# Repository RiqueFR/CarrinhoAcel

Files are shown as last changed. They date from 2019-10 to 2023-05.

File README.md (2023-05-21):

# CarrinhoAcel

Este projeto consiste no projeto de um robô/carrinho controlado remotamente por meio de comunicação Bluetooth e os dados lidos de um acelorômetro, que foi preso a uma luva sendo assim responsável por direcionar o robô conforme a inclinação da mão do condutor.</br>
O projeto foi desenvolvido para a disciplina de Projeto Integrado de Computação, no segundo período do curso de Engenharia de Computação da UFES.

## Esquemático

No diretório "Esq_Eagle" é possível encontrar o esquemático eletrônico desenvolvido tanto para a luva quanto para o carrinho, em seus respectivos diretórios.

## Funcionamento

O projeto funciona basicamente da seguinte forma, um Arduíno lê os dados do sensor de acelerômetro, transforma esses dados em uma direção, representada por um caractér, e um valor entre 0 e 1, que representa o quão inclinada está a luva.
Esses dado são passados via Bluetooth para outro Arduíno que está no robô, e ele controla a velocidade dos motores de acordo com a direção e o decimal recebido, que representa uma porcentagem da velocidade dele.

## Outros

É possível ver mais informações do projeto no documento "Henrique_Thiago_Henrique.pdf", que foi o arquivo enviado como relatório para o professor da disciplina.

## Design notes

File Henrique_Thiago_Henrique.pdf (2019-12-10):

UNIVERSIDADE FEDERAL DO ESPÍRITO SANTO CAMPUS VITÓRIA - GOIABEIRAS

Alunos: Henrique Faria Ribeiro, Henrique Paulino Cruz e Thiago Tineli Paiva Disciplina: Projeto Integrador em Computação I
Docente: Vinicius Fernandes Soares Mota
Data: 11/12/2019

PROJETO

O projeto inicialmente foi desenvolvido na parte de software, para o controle da ponte H, projeção da comunicação via Bluetooth e o tratamento de valores do acelerômetro.
Após o desenvolvimento dessa parte, foi adaptado um carrinho, para o uso no projeto, também foi realizado os esquemáticos para a luva e o carrinho.
Finalmente, ocorreu a integração entre Hardware e Software, com a confecção das placas para o projeto e sua implementação nas peças.

ESQUEMÁTICOS

❏ Ligação na luva

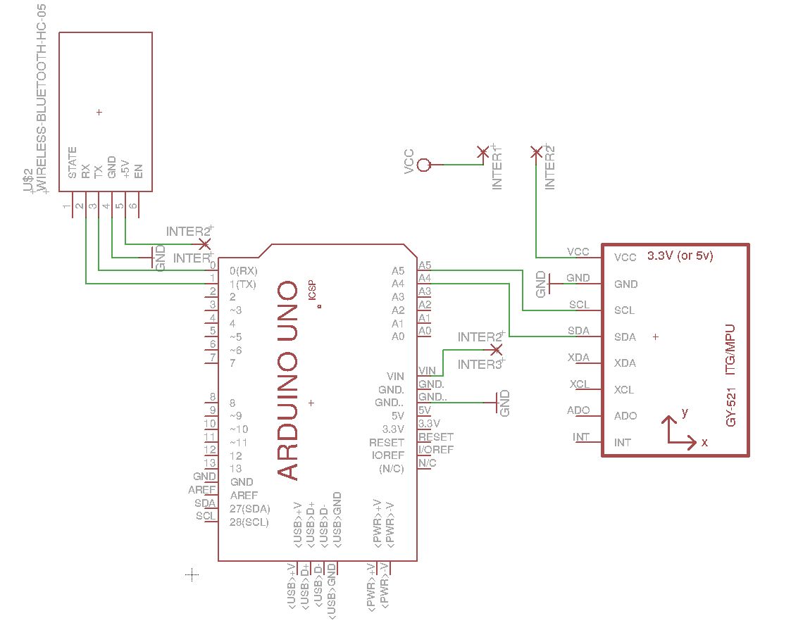
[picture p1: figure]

❏ Ligação no carrinho

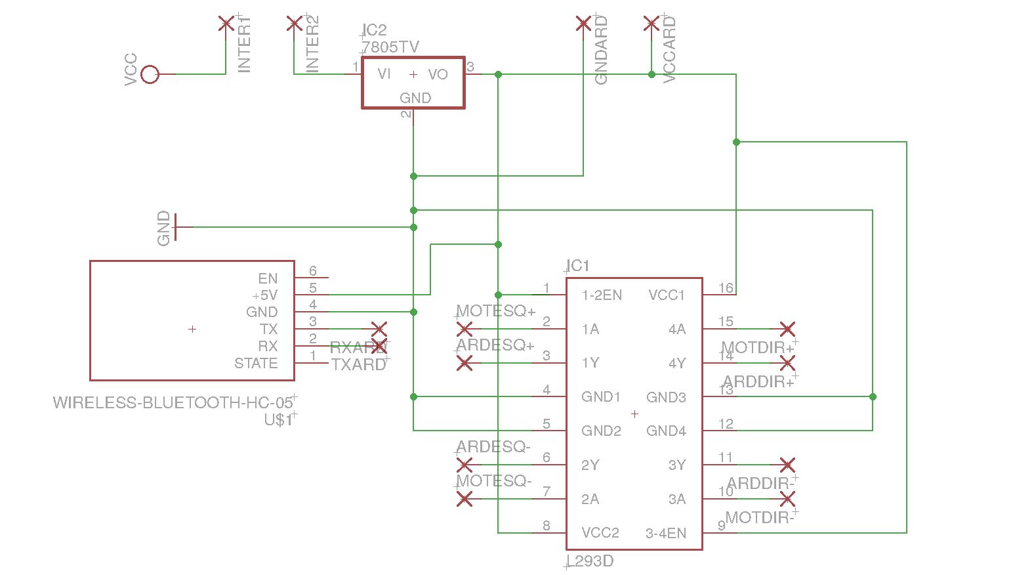
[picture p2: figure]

Obs: nesse esquemático as portas que ligariam no arduino estão representados como PADs, pois se fosse colocado o arduíno no esquemático ele ficaria menos legível, atrapalhando a compreensão.

COMPONENTES

Eletrônico:
❏ Arduino UNO - 2 unidades
❏ Ponte H - 1 unidade
❏ Bateria - 4 células de bateria de notebook ❏ Motor com redução e rodas - 2 unidades ❏ Acelerômetro - 1 unidade
❏ Bluetooth HC-05 - 2 unidades
❏ Chaves - 2 unidades
❏ Placa de circuito impresso - 2 unidades ❏ Jumpers

Outros:
❏ Luva - 1 unidade
❏ Madeira

EXPERIÊNCIA

Nós consideramos a experiência do trabalho como positiva, devido as diferentes áreas exploradas durante a sua construção, como a comunicação entre embarcados, controle de motores e conversão de valores para adaptação do projeto. Destarte, foi um aprendizado excepcional e extremamente útil para futuros projetos e disciplinas.

DIFICULDADES

Neste tópico irei abordar algumas dificuldades encontradas durante a execução do trabalho.
O principal problema que nos deparamos foi com alguns dos componentes que compramos ou estávamos usando queimaram, dentre eles está 1 Arduino Micro, 1 acelerômetro e 1 Ponte H. Graças a isso, tivemos algum pequeno atraso.
Também devido a esse problema, tivemos que alterar o Arduino Micro, que seria utilizado na luva, pois ele queimou e não tínhamos tempo para encomendar outro do mesmo modelo. Portanto optamos por utilizar outro Arduino Uno que foi fornecido pelo professor. Tivemos que alterar também a Ponte H utilizada, antes usamos o modelo L293D, que é um modelo compacto em forma de CI, e tivemos que trocar para o modelo disponível, cedido pelo PET Engenharia de Computação, que é um modelo mais robusto, o L293N. Ele ocupou muito do espaço disponível no carrinho, então tivemos que improvisar a distribuição dos outros componentes e não utilizar a tampa dele.

LINKS

❏ GitHub do projeto:

https://github.com/RiqueFR/CarrinhoAcel

❏ Vídeo para o projeto funcionando:

https://drive.google.com/open?id=1_wqeDYMHRfp-zv_wWewBiIVHSZSvfsvn

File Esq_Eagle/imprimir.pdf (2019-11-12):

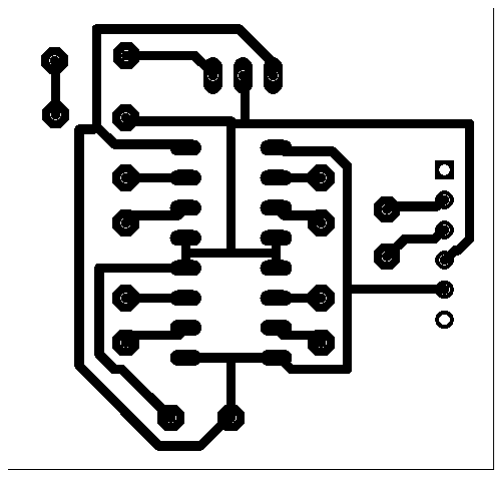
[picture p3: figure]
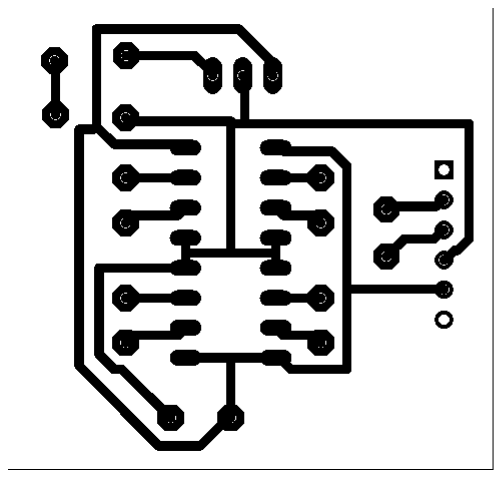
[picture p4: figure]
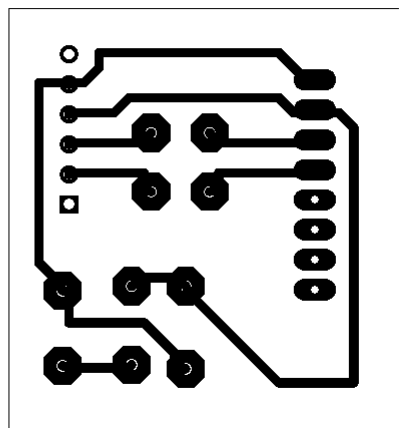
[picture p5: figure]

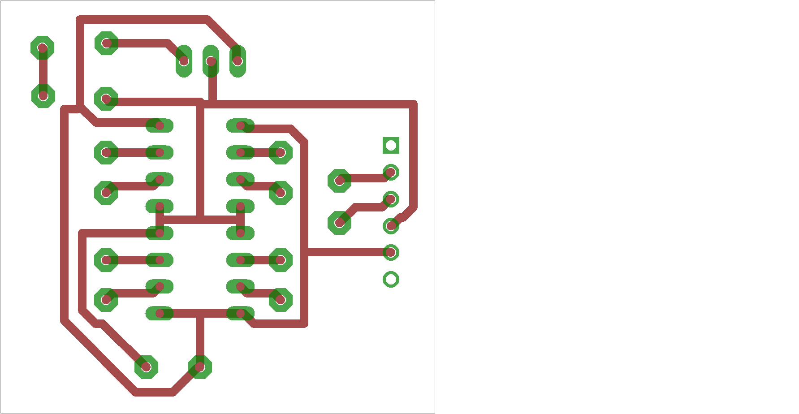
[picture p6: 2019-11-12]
Esq_Eagle/Carrinho/RogerThat.png

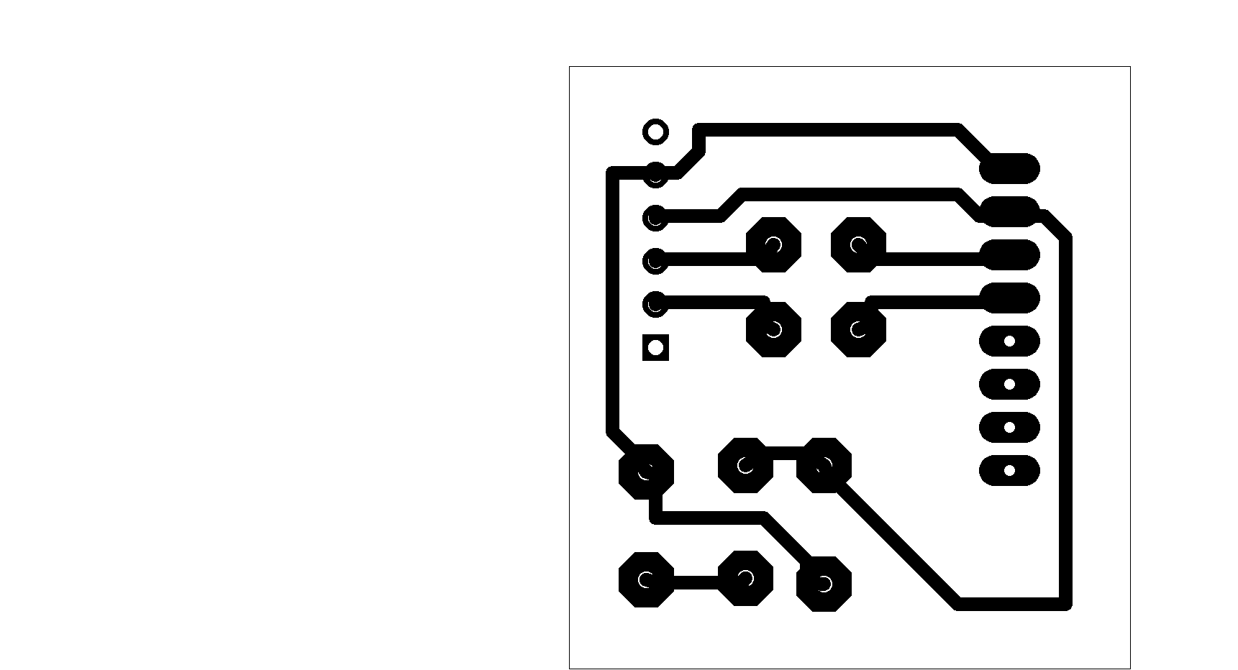
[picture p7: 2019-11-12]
Esq_Eagle/Luva/LuvaEsq.png

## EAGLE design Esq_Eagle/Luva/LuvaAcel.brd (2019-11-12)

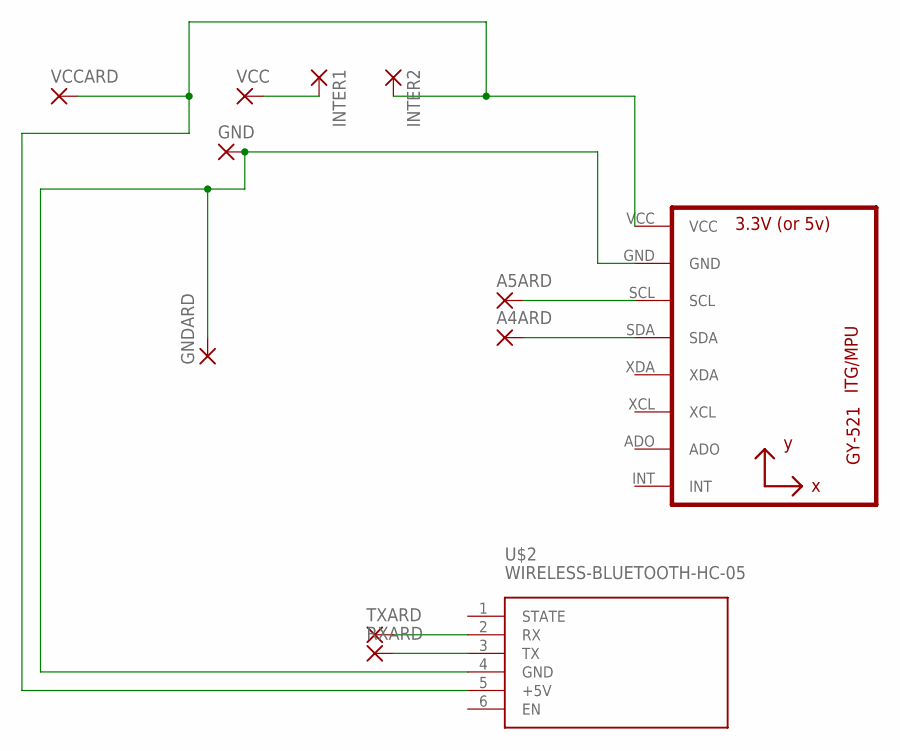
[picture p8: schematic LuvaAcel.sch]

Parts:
A4ARD, A5ARD: 3,17/1,1
GND: 3,17/1,1
GNDARD: 3,17/1,1
INTER1, INTER2: 3,17/1,1
RXARD: 3,17/1,1
TXARD: 3,17/1,1
U1: GY-521MPU6050; GY-521
U$2: WIRELESS-BLUETOOTH-HC-05
VCC: 3,17/1,1
VCCARD: 3,17/1,1

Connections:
unnamed: A5ARD.1, U1.SCL
unnamed: A4ARD.1, U1.SDA
unnamed: GND.1, GNDARD.1, U1.GND, U$2.4 (GND)
unnamed: TXARD.1, U$2.2 (RX)
unnamed: RXARD.1, U$2.3 (TX)
unnamed: INTER2.1, U1.VCC, U$2.5 (+5V), VCCARD.1
unnamed: INTER1.1, VCC.1

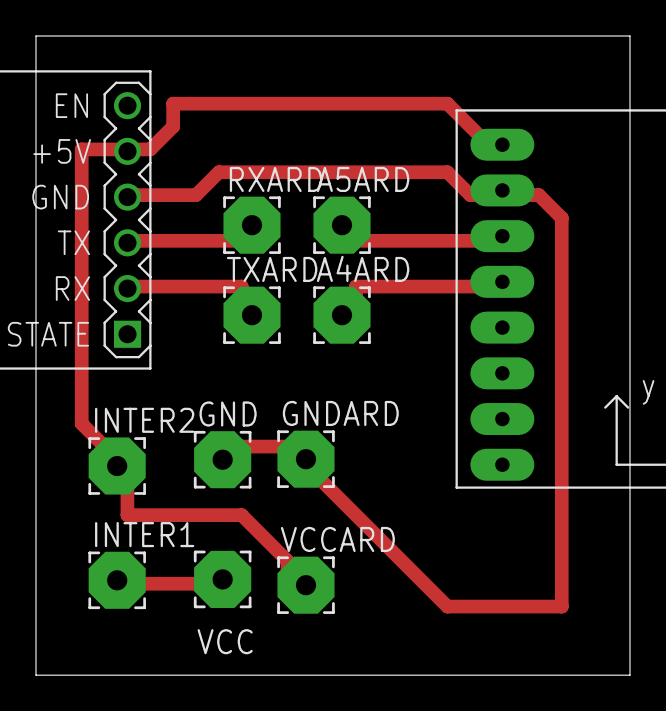
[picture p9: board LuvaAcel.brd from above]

Board: 2 copper layers, 33.0 x 35.5 mm, 12 parts (0 on the bottom side), 7 nets.

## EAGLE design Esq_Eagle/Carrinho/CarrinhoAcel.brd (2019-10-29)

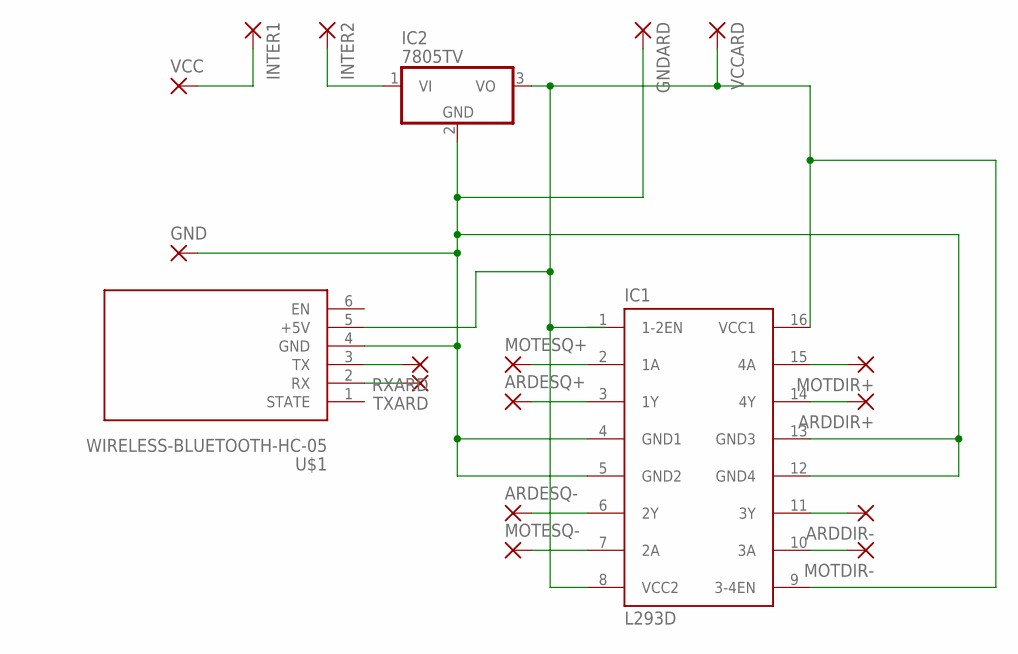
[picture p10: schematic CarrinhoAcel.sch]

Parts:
ARDDIR+: 2,15/1,0
ARDDIR-: 2,15/1,0
ARDESQ+: 2,15/1,0
ARDESQ-: 2,15/1,0
GND: 2,15/1,0
GNDARD: 2,15/1,0
IC1: L293D; DIL16
IC2: 7805TV; TO220V
INTER1, INTER2: 2,15/1,0
MOTDIR+: 2,15/1,0
MOTDIR-: 2,15/1,0
MOTESQ+: 2,15/1,0
MOTESQ-: 2,15/1,0
RXARD: 2,15/1,0
TXARD: 2,15/1,0
U$1: WIRELESS-BLUETOOTH-HC-05
VCC: 2,15/1,0
VCCARD: 2,15/1,0

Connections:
unnamed: INTER1.1, VCC.1
unnamed: GND.1, GNDARD.1, IC1.4 (GND1), IC1.5 (GND2), IC1.12 (GND4), IC1.13 (GND3), IC2.2 (GND), U$1.4 (GND)
unnamed: IC1.2 (1A), MOTESQ+.1
unnamed: ARDESQ+.1, IC1.3 (1Y)
unnamed: ARDESQ-.1, IC1.6 (2Y)
unnamed: IC1.7 (2A), MOTESQ-.1
unnamed: IC1.1 (1-2EN), IC1.8 (VCC2), IC1.9 (3-4EN), IC1.16 (VCC1), IC2.3 (VO), U$1.5 (+5V), VCCARD.1
unnamed: IC1.10 (3A), MOTDIR-.1
unnamed: ARDDIR-.1, IC1.11 (3Y)
unnamed: ARDDIR+.1, IC1.14 (4Y)
unnamed: IC1.15 (4A), MOTDIR+.1
unnamed: RXARD.1, U$1.3 (TX)
unnamed: IC2.1 (VI), INTER2.1
unnamed: TXARD.1, U$1.2 (RX)

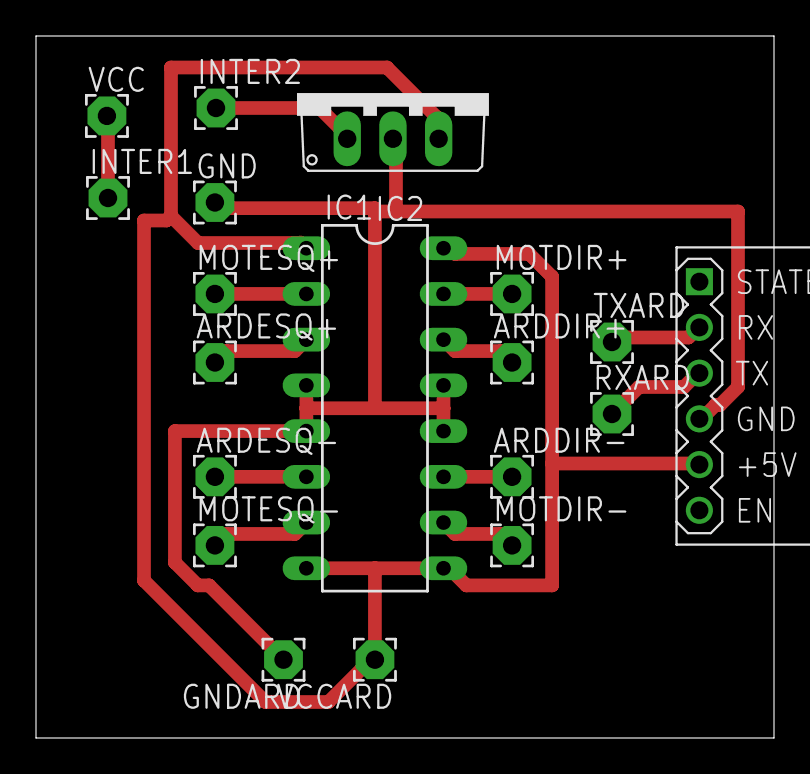
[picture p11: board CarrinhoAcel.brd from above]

Board: 2 copper layers, 41.0 x 39.0 mm, 19 parts (0 on the bottom side), 14 nets.

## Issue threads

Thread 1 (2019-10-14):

Sobre as variáveis sendo enviadas para o carrinho.

ThiagoPaiva27, 2019-10-14:
Nós podemos fazer com que seja enviada somente uma variável para o carrinho, para facilitar a comunicação entre os dois arduinos

Ex: no void loop do carrinho podemos fazer com que a variável resete a cada ciclo para "init", no qual faz o carrinho parar, e no início do ciclo abra um espaço para receber a variável da luva(comando = esquerda, comando = direita....)
Nota: o programa é tão rápido que não é necessário esperar para receber o comando, então pode-se dispensar o espaço para delays

Closed 2019-10-17.

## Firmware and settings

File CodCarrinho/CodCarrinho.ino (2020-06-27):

#define enA 5
#define enB 6
#define pinMotor1 9
#define pinMotor2 10
#define pinMotor3 11
#define pinMotor4 12

/*Função que faz o controle de velocidade dos motore, para que quando 
mais inclinada a luva estiver, mais rápido o carrinho ande.*/
int converteData(float data) {
    if (data < 0) data = -data;
    return 255 * data;
}

void setup() {
    int i;
    pinMode(pinMotor1, OUTPUT);
    pinMode(pinMotor2, OUTPUT);
    pinMode(pinMotor3, OUTPUT);
    pinMode(pinMotor4, OUTPUT);
    Serial.begin(38400);
}

void loop() {
    //Comunicação para receber direção e angulação
    float val = 0;
    int cont = 0, numC = 0;
    bool ehposs = false;
    char let = 'N';

    /*Verifica se o serial está disponível para leitura dos dados enviado pela luva, 
    quantos bytes possuem, e armazena essa quantdade em "numC"*/
    numC = Serial.available();
    if (numC) {
        //Faz a leitura dos dados;
        char c[numC];
        while (cont <= numC) {
            c[cont] = (char)Serial.read();
            cont++;
        }
        let = c[0];
        cont = 0;

        /*A luva envia uma string do tipo "X- 0.48", por exemplo, 
        então devemos tratar esse dado e transformá-lo em um decimal.*/
        if (c[0] == 'X' || c[0] == 'Y' || c[0] == 'N') {
            if (c[1] == '-') {
                val += c[2] - '0';
                val += (c[4] - '0') / 10.0;
                val += (c[5] - '0') / 100.0;
                val *= -1;
            } else {
                val += c[1] - '0';
                val += (c[3] - '0') / 10.0;
                val += (c[4] - '0') / 100.0;
            }
            //Filtra o valor recebido, para caso a luva transmita um dado diferente do esperado
            if (val >= -1 && val <= 1) {
                ehposs = true;
            } else {
                ehposs = false;
            }
        }
    }

    delay(50);
    float data = val;
    char direcao = let;
    /*Uso de condições para direções e convertData para tratamento da angulacao para velocidade*/
    if (ehposs) {
        Serial.println(converteData(data));
        if (direcao == 'X' && data < 0) {
            //INVERTE DIRECAO RODA DIREITA
            digitalWrite(pinMotor1, LOW);
            digitalWrite(pinMotor2, HIGH);
            digitalWrite(pinMotor3, HIGH);
            digitalWrite(pinMotor4, LOW);
            analogWrite(enA, converteData(data));
            analogWrite(enB, converteData(data));
        } else if (direcao == 'X' && data > 0) {
            //INVERTE DIRECAO RODA ESQUERDA
            digitalWrite(pinMotor1, HIGH);
            digitalWrite(pinMotor2, LOW);
            digitalWrite(pinMotor3, LOW);
            digitalWrite(pinMotor4, HIGH);
            analogWrite(enA, converteData(data));
            analogWrite(enB, converteData(data));
        } else if (direcao == 'Y' && data < 0) {
            //INVERTE DIRECAO RODA FRENTE
            digitalWrite(pinMotor1, LOW);
            digitalWrite(pinMotor2, HIGH);
            digitalWrite(pinMotor3, LOW);
            digitalWrite(pinMotor4, HIGH);
            analogWrite(enA, converteData(data));
            analogWrite(enB, converteData(data));
        } else if (direcao == 'Y' && data > 0) {
            //INVERTE DIRECAO DAS RODAS RÉ
            digitalWrite(pinMotor1, HIGH);
            digitalWrite(pinMotor2, LOW);
            digitalWrite(pinMotor3, HIGH);
            digitalWrite(pinMotor4, LOW);
            analogWrite(enA, converteData(data));
            analogWrite(enB, converteData(data));
        } else {
            digitalWrite(pinMotor1, LOW);
            digitalWrite(pinMotor2, LOW);
            digitalWrite(pinMotor3, LOW);
            digitalWrite(pinMotor4, LOW);
        }
    }
}

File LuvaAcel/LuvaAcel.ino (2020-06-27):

// Acelerômetro ADXL345
#include <Wire.h>

#define Register_ID 0
#define Register_2D 0x2D
#define Register_X0 0x32
#define Register_X1 0x33
#define Register_Y0 0x34
#define Register_Y1 0x35
#define Register_Z0 0x36
#define Register_Z1 0x37

/*Define uma tolerância na inclinação para que qualquer movimento
simples não seja interpretado como um comando.*/
#define TOL 0.3f

//Endereco I2C do sensor : 83 em decimal ou 0x53
int ADXAddress = 0x53;  //Endereço 7-bit do sensor I2C
int reading = 0;
int val = 0;
int X0, X1, X_out;
int Y0, Y1, Y_out;
int Z1, Z0, Z_out;
double Xg, Yg, Zg;

void RecebeAcel();

void setup() {
    Wire.begin();
    Serial.begin(38400);
    delay(100);
    Wire.beginTransmission(ADXAddress);  //Inicia a transmissão com o dispositivo I2C
    Wire.write(Register_2D);
    Wire.write(8);
    Wire.endTransmission();  //Finaliza transmissão
}

void loop() {
    /*Faz a leitura do acelerômetro e depois escreve na porta serial a leitura do mesmo, 
    isso já é o suficiente para que o bluetooth do carrinho consiga receber os dados.*/
    RecebeAcel();
    if (Xg > TOL || Xg < -TOL || Yg < -TOL || Yg > TOL) {
        if (Yg < -TOL && Yg >= -1) {  //Frente
            Serial.print("Y");
            Serial.println(Yg);
        } else if (Yg > TOL && Yg <= 1) {  //Tras
            Serial.print("Y");
            Serial.println(Yg);
        } else if (Xg > TOL && Xg <= 1) {  //Direita
            Serial.print("X");
            Serial.println(Xg);
        } else if (Xg < -TOL && Xg >= -1) {  //Esquerda
            Serial.print("X");
            Serial.println(Xg);
        }
    } else {
        Serial.print("N");
        Serial.println(0.0);
    }

    delay(100);
}

//Função que recebe e interpreta os dados do acelerômetro
void RecebeAcel() {
    //------------------X
    Wire.beginTransmission(ADXAddress);
    Wire.write(Register_X0);
    Wire.write(Register_X1);
    Wire.endTransmission();
    Wire.requestFrom(ADXAddress, 2);
    if (Wire.available() <= 2) {
        X0 = Wire.read();
        X1 = Wire.read();
        X1 = X1 << 8;
        X_out = X0 + X1;
    }

    //------------------Y
    Wire.beginTransmission(ADXAddress);
    Wire.write(Register_Y0);
    Wire.write(Register_Y1);
    Wire.endTransmission();
    Wire.requestFrom(ADXAddress, 2);
    if (Wire.available() <= 2) {
        Y0 = Wire.read();
        Y1 = Wire.read();
        Y1 = Y1 << 8;
        Y_out = Y0 + Y1;
    }
    //------------------Z
    Wire.beginTransmission(ADXAddress);
    Wire.write(Register_Z0);
    Wire.write(Register_Z1);
    Wire.endTransmission();
    Wire.requestFrom(ADXAddress, 2);
    if (Wire.available() <= 2) {
        Z0 = Wire.read();
        Z1 = Wire.read();
        Z1 = Z1 << 8;
        Z_out = Z0 + Z1;
    }

    Xg = X_out / 256.0;
    Yg = Y_out / 256.0;
    Zg = Z_out / 256.0;
}

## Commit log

2019-10-08 Adicionado código simples para luva
2019-10-17 Modificando arquivo CodCarrinho para CodCarrinho.ino e movendo ele para sua pasta
2019-10-24 Funcionando, precisad
    [CarrinhoAcel.brd, CarrinhoAcel.sch]
2019-10-29 Adicionando esquematico
    [CarrinhoAcel.brd, CarrinhoAcel.sch, LuvaAcel.brd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]
2019-10-29 Removendo os esquematicos antigos
    [CarrinhoAcel.brd, CarrinhoAcel.sch]
2019-10-31 Adicionando codigo para RGB
2019-11-12 gerando arquivo para impressao das placas
    [LuvaAcel.brd, LuvaAcel.sch]

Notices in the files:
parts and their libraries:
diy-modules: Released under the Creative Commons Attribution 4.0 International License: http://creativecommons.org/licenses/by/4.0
